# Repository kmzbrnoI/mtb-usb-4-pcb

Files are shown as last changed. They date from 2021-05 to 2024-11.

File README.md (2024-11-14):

MTB-USB v4 PCB
==============

MTB-USB is a [MTBbus](https://mtb.kmz-brno.cz/bus) to USB interface.
It connects computer to the MTBbus. It is a master module on the MTBbus.

This repository contains schematics & PCB layout of MTB-USB v4 PCB. Firmware
for main MCU STM32F103 is available
[here](https://github.com/kmzbrnoI/mtb-usb-4-fw). More information about
MTB in available [here](https://mtb.kmz-brno.cz/).

## Design

Schematics & PCB are designed in KiCad 8.

## Production

PCB is prepared to be automatically assembled in [JLCPCB](https://jlcpcb.com/).
SMD parts on **top** side should be assembled. Each SMD part has its `LCSC_ITEM`
attribute set.

```bash
$ kikit fab jlcpcb --assembly --schematic mtb-usb-4-ele.sch mtb-usb-4-ele.kicad_pcb fab
```

## Parameters

 * Galvanically separated USB & MTBbus.
 * USB-C connector.
 * USB part (with main MCU): powered directly from USB-C connector. No need
   for voltage over 5V (old USB compatibility ok).
 * MTBbus powered either from outside (7–17 V, ideally 12 V) or from USB
   via galvanically-separated DC-DC convertor.
   - GND must be connected with MTBbus' GND always!
 * MTBbus terminator on-board.
 * Two RJ12 connectors as well as screw terminals for MTBbus connection.
 * Max power consumption: 300 mA.
   - Max current through RS485 driver: 250 mA.

## Authors

MTB-USB v4 module is designed by [Model Railroaders Club
Brno](https://www.kmz-brno.cz/), [Jan Horáček](mailto:jan.horacek@kmz-brno.cz).

## License

Content of the repository is provided under [Creative Commons
Attribution-ShareAlike 4.0
License](https://creativecommons.org/licenses/by-sa/4.0/) as openhardware
project. You may download any data, contribute to the project, create PCB
yourself or even sell it yourself.

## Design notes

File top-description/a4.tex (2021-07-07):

\documentclass[12pt,a4paper,landscape]{article}
\usepackage[czech]{babel}
\usepackage[utf8]{inputenc}
\usepackage[T1]{fontenc}
\usepackage{lmodern}
\usepackage{microtype}
\usepackage{graphicx}
\textwidth 28cm \textheight 24.6cm
\topmargin -2cm
\oddsidemargin 0cm

\begin{document}
\pagestyle{empty}
\setlength{\parindent}{0cm}
\setlength{\parskip}{3mm plus2pt minus2pt}

\noindent












\end{document}

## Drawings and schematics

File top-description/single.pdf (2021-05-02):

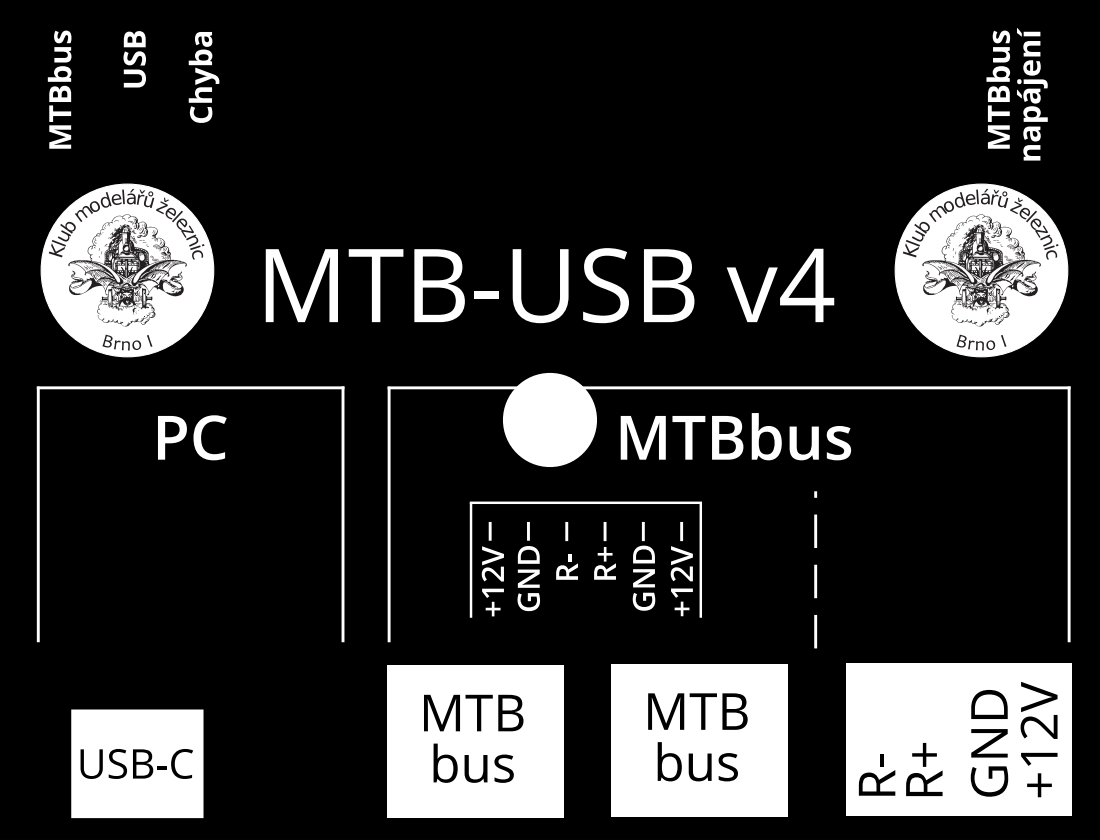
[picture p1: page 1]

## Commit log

2021-02-03 Add project, empty schematics, empty pcb.
    [mtb-usb-4-ele.kicad_pcb, mtb-usb-4-ele.sch]
2021-02-03 Add components to schematics.
    [mtb-usb-4-ele.sch]
2021-02-04 Sch: add rest of parts.
    [mtb-usb-4-ele.sch]
2021-02-04 Sch: reposition parts.
    [mtb-usb-4-ele.sch]
2021-02-04 Add packages, add LCSC, connect LEDs.
    [mtb-usb-4-ele.sch]
2021-02-04 Decrease LED resistors resistance to 1kOhm.
    [mtb-usb-4-ele.sch]
2021-02-04 Comment on power supply, annotate parts.
    [mtb-usb-4-ele.sch]
2021-02-04 Add solder jumpers on DC-DC convertor.
    [mtb-usb-4-ele.sch]
2021-02-04 Add "no connection" to NC pins.
    [mtb-usb-4-ele.sch]
2021-02-05 Sch: connect VBAT & VDDA, add capactitor.
    [mtb-usb-4-ele.sch]
2021-02-05 Name wires consistently.
    [mtb-usb-4-ele.sch]
2021-02-05 Add BOOT0 jumper.
    [mtb-usb-4-ele.sch]
2021-02-07 Sch: add PWR_FLAG.
    [mtb-usb-4-ele.sch]
2021-02-07 Sch: add proper frame, add jumper footprint.
    [mtb-usb-4-ele.sch]
2021-02-07 Sch: bus: change stabilizer for ≥ 250 mA.
    250 mA is drained by ADM2483 when RS485 is shorted.
    [mtb-usb-4-ele.sch]
2021-02-08 Sch: remove MCP130T.
    Bus does not have to be in defined state when MTB-USB is booting up as
    these is surely no communication over the bus without master module
    active.
    [mtb-usb-4-ele.sch]
2021-02-09 Add bus current measuring.
    [mtb-usb-4-ele.sch]
2021-02-09 Sch: measure current only through ADM2483.
    [mtb-usb-4-ele.sch]
2021-02-11 Initialize pcb.
    [mtb-usb-4-ele.kicad_pcb]
2021-02-11 PCB: add polygons.
    [mtb-usb-4-ele.kicad_pcb]
2021-02-24 Add real PCB based based on box size.
    [mtb-usb-4-ele.kicad_pcb]
2021-02-24 Use connectors matching box size.
    [mtb-usb-4-ele.kicad_pcb, mtb-usb-4-ele.sch]
2021-02-24 Group parts in their areas.
    [mtb-usb-4-ele.kicad_pcb, mtb-usb-4-ele.sch]
2021-02-24 Route MCU part.
    [mtb-usb-4-ele.kicad_pcb, mtb-usb-4-ele.sch]
2021-02-25 Route whole PCB.
    [mtb-usb-4-ele.kicad_pcb, mtb-usb-4-ele.sch]
2021-02-28 Add bottom GND polygon, add vias.
    [mtb-usb-4-ele.kicad_pcb]
2021-03-01 Place silkscreen descriptions.
    [mtb-usb-4-ele.kicad_pcb]
2021-03-01 Switch R+ & R- on RJ connectors.
    [mtb-usb-4-ele.kicad_pcb, mtb-usb-4-ele.sch]
2021-03-01 Fix DRC issues.
    [mtb-usb-4-ele.kicad_pcb]
2021-03-01 Cleanup tracks & vias.
    [mtb-usb-4-ele.kicad_pcb]
2021-03-01 Change isolation space to 2.5 mm.
    Change DC-DC convertor to larger package to achieve larger pads
    distance.
    [mtb-usb-4-ele.kicad_pcb, mtb-usb-4-ele.sch]
2021-03-01 Add testpads.
    [mtb-usb-4-ele.kicad_pcb, mtb-usb-4-ele.sch]
2021-03-01 Sch: add note about current.
    [mtb-usb-4-ele.sch]
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2021-03-01 Add two test pins from CPU.
    [mtb-usb-4-ele.kicad_pcb, mtb-usb-4-ele.sch]
2021-03-01 Move JP5 to leave space for DC-DC convertor.
    [mtb-usb-4-ele.kicad_pcb]
2021-03-01 Minor fixes.
    [mtb-usb-4-ele.kicad_pcb]
2021-03-01 Move USB connector to edge of PCB.
    [mtb-usb-4-ele.kicad_pcb, mtb-usb-4-ele.sch]
2021-03-02 Add USB ESD protection.
    [mtb-usb-4-ele.kicad_pcb, mtb-usb-4-ele.sch]
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2021-03-02 Add testpad silkscreen descriptions.
    [mtb-usb-4-ele.kicad_pcb]
2021-03-02 Fix silkscreen.
    [mtb-usb-4-ele.kicad_pcb, mtb-usb-4-ele.sch]
2021-03-24 Bus: fix power connector position.
    [mtb-usb-4-ele.kicad_pcb]
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2021-03-24 Make holes for ring testpins smaller.
    [mtb-usb-4-ele.kicad_pcb, mtb-usb-4-ele.sch]
2021-03-31 Add missing resistor to USB-D+ pin.
    [mtb-usb-4-ele.kicad_pcb, mtb-usb-4-ele.sch]
2021-04-01 Fix LSCS for 5k1 resistors.
    [mtb-usb-4-ele.sch]
2021-04-06 Fix order of R+ & R- in RJ11 connectors.
    [mtb-usb-4-ele.kicad_pcb, mtb-usb-4-ele.sch]
2021-04-06 Fix position on silkscreen description of testpads.
    [mtb-usb-4-ele.kicad_pcb]
2021-04-06 Write connector pinouts to silkscreen.
    [mtb-usb-4-ele.kicad_pcb]
2021-04-06 Add solder jumper for output of stabilisator on bus part.
    [mtb-usb-4-ele.kicad_pcb, mtb-usb-4-ele.sch]
2021-04-06 PCB: add polygon for manufacturing info.
    [mtb-usb-4-ele.kicad_pcb]
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2021-05-02 Mark debug pins "A" and "B".
    [mtb-usb-4-ele.kicad_pcb]
2021-06-04 Add JLCPCB tooling holes.
    [mtb-usb-4-ele.kicad_pcb, mtb-usb-4-ele.sch]
2021-11-06 MTBbus: add ESD protection.
    [mtb-usb-4-ele.kicad_pcb, mtb-usb-4-ele.sch]
2021-12-28 Add missing no-connections.
    [mtb-usb-4-ele.sch]
2022-01-25 Migrate to KiCad 6.
    [mtb-usb-4-ele.kicad_pcb, mtb-usb-4-ele.kicad_sch, mtb-usb-4-ele.sch]
2022-01-25 Add green LED, add JLCPCB_IGNORE.
    [mtb-usb-4-ele.kicad_sch]
2022-01-25 Set board stackup colors.
    [mtb-usb-4-ele.kicad_pcb]
2022-02-28 AM2D-0505: allow both SZ&DZ variants: add solderjumper.
    [mtb-usb-4-ele.kicad_pcb, mtb-usb-4-ele.kicad_sch]
2022-07-16 Add safety resistor & capacitor between grounds.
    [mtb-usb-4-ele.kicad_pcb, mtb-usb-4-ele.kicad_sch]
2024-11-14 Migrate to KiCad 8.
    [mtb-usb-4-ele.kicad_sch]
2024-11-14 Adjust LED resistors.
    * 5V blue: 4k7.
    * 3V3 blue: 2k2.
    * 3V3 green: 10k.
    [mtb-usb-4-ele.kicad_pcb, mtb-usb-4-ele.kicad_sch]
2024-11-14 TME part id as a part's property.
    [mtb-usb-4-ele.kicad_pcb, mtb-usb-4-ele.kicad_sch]
2024-11-14 MCU: remove power BVAT, VDDA, remove C7.
    This board does not have battery and does not use ADC.
    [mtb-usb-4-ele.kicad_pcb, mtb-usb-4-ele.kicad_sch]
2024-11-14 Add USB polyfuse 500 mA F1.
    [mtb-usb-4-ele.kicad_pcb, mtb-usb-4-ele.kicad_sch]
2024-11-14 Do not populace terminator R15.
    [mtb-usb-4-ele.kicad_sch]
2024-11-14 Screw terminals: use exact part value.
    [mtb-usb-4-ele.kicad_pcb, mtb-usb-4-ele.kicad_sch]
2024-11-14 Add fuse F2 for MTBbus power.
    [mtb-usb-4-ele.kicad_pcb, mtb-usb-4-ele.kicad_sch]
2024-11-14 Note RJ12 GME & TME part names.
    [mtb-usb-4-ele.kicad_pcb, mtb-usb-4-ele.kicad_sch]
